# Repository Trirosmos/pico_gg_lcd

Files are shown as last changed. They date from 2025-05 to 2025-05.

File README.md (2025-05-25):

## Pico GG LCD

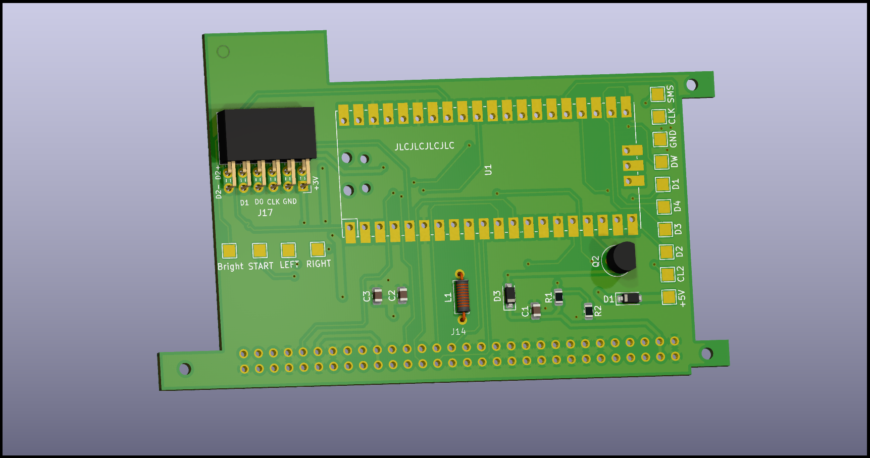
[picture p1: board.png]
install_image


RP2040-based Game Gear screen replacement kit.
Even a cheapo modern LCD has much, much, much better contrast ratio than the OG screen.

## Building the software

Clone this repository and pull all submodules:
```Bash
git clone https://github.com/Trirosmos/pico_gg_lcd
cd pico_gg_lcd
git submodule update --init --recursive
```

Then, run `sw/build.sh`:

```Bash
cd sw
mkdir build
cd build
cmake ../CMakeLists.txt
make
```

This should generate an uf2 file you can upload to the RP2040;

## Building the hardware

Componentes you'll need and their approximate cost:

- Pico GG LCD PCB ($5)
- [PMOD HDMI adapter board](https://aliexpress.com/w/wholesale-pmod%2525252dhdmi.html?spm=a2g0o.detail.search.0) ($4) 
- [54-pin FPC connector adapter board](https://aliexpress.com/item/32827105259.html) ($2)
- [LQ035NC111 LCD module](https://aliexpress.com/w/wholesale-LQ035NC111.html?spm=a2g0o.home.search.0) ($10)
- [RP2040 board that exposes all 30 GPIOs](https://aliexpress.com/item/1005003796653297.html) ($4)
- BS170 or similar NMOSFET ($0.3)
- ~470uH axial THT inductor ($0.2)
- 2x SOD-123 Schottky diode ($0.4)
- 10k 0805 resistor ($0.05)
- 100k 0805 resistor ($0.05)
- 100nF 0805 resistor ($0.05)
- 100uF 0805 resistor ($0.05)
- 22uF 0805 resistor ($0.05)

Total approximate BOM cost: $26

First assemble passive components and transistor, then the RP2040 board and leave the FPC connector to be connected last.
The final board should look something like this, sans the bodge wire:

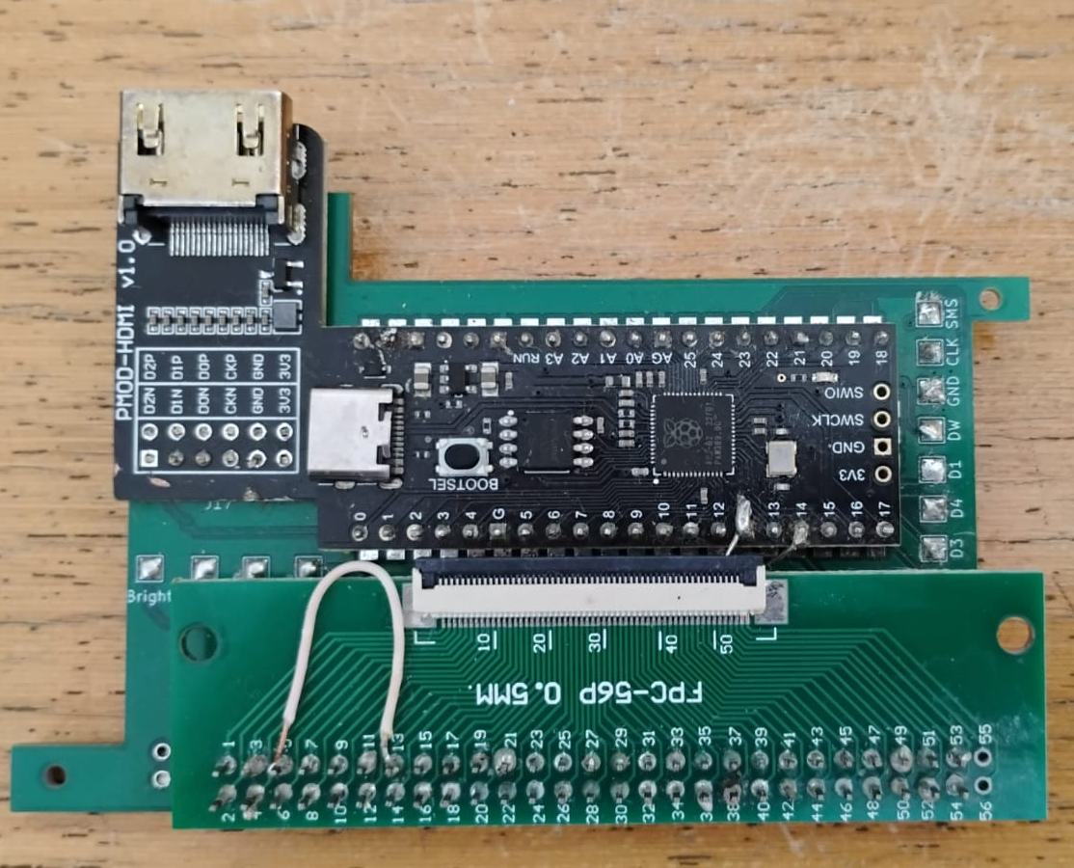
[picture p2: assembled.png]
board_assembly


## How Game Gear video signals work

The Game Gear ASIC generates digital video signals that the LCD drivers in the LCD ribbon use to drive the actual display segments.

In NTSC mode, i.e, when test pad T10 is connected to +5V, the timings of the signals from the ASIC closely resemble what one would expect from a console like the Master System. All screen replacement kits run the Game Gear in this mode, as far as I'm aware. 

The communication protocol used between the ASIC and the LCD drivers in this mode is [well documented](https://www.retrosix.wiki/va0va1-lcd-interface-game-gear) and essentially boils down to:

- 32 MHz pixel clock (same as the main system clock)
- 4 bit data bus carrying one channel of color data at a time
- VSync signal
- HSync signal

## How the RP2040 captures GG video

One of the PIOs is takes alongside three DMA channels with building a live framebuffer in RAM with the image data the GG is sending out.

Three PIO SMs are used in the following manner:

- SM0 detects when a frame starts and triggers an IRQ.
- SM1 detects the IRQ from SM0 and starts detecting HSync pulses. It triggers an IRQ when it does.
- SM2 detects the IRQ from SM1 and proceeds to capture pixel data and push it out to the RX FIFO.

One of the DMA channels then takes the 12bpp pixel data from the PIO RX FIFO and saves it into RAM.

Finally, one of the CPU cores upscales the image and sends it out to the LCD.

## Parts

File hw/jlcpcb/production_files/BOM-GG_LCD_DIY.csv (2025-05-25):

Comment | Designator | Footprint | LCSC
Conn_02x06_Odd_Even | J17 | PinSocket_2x06_P2.54mm_Horizontal | C124371
D_Schottky | D1 | D_SOD-123 | C8598

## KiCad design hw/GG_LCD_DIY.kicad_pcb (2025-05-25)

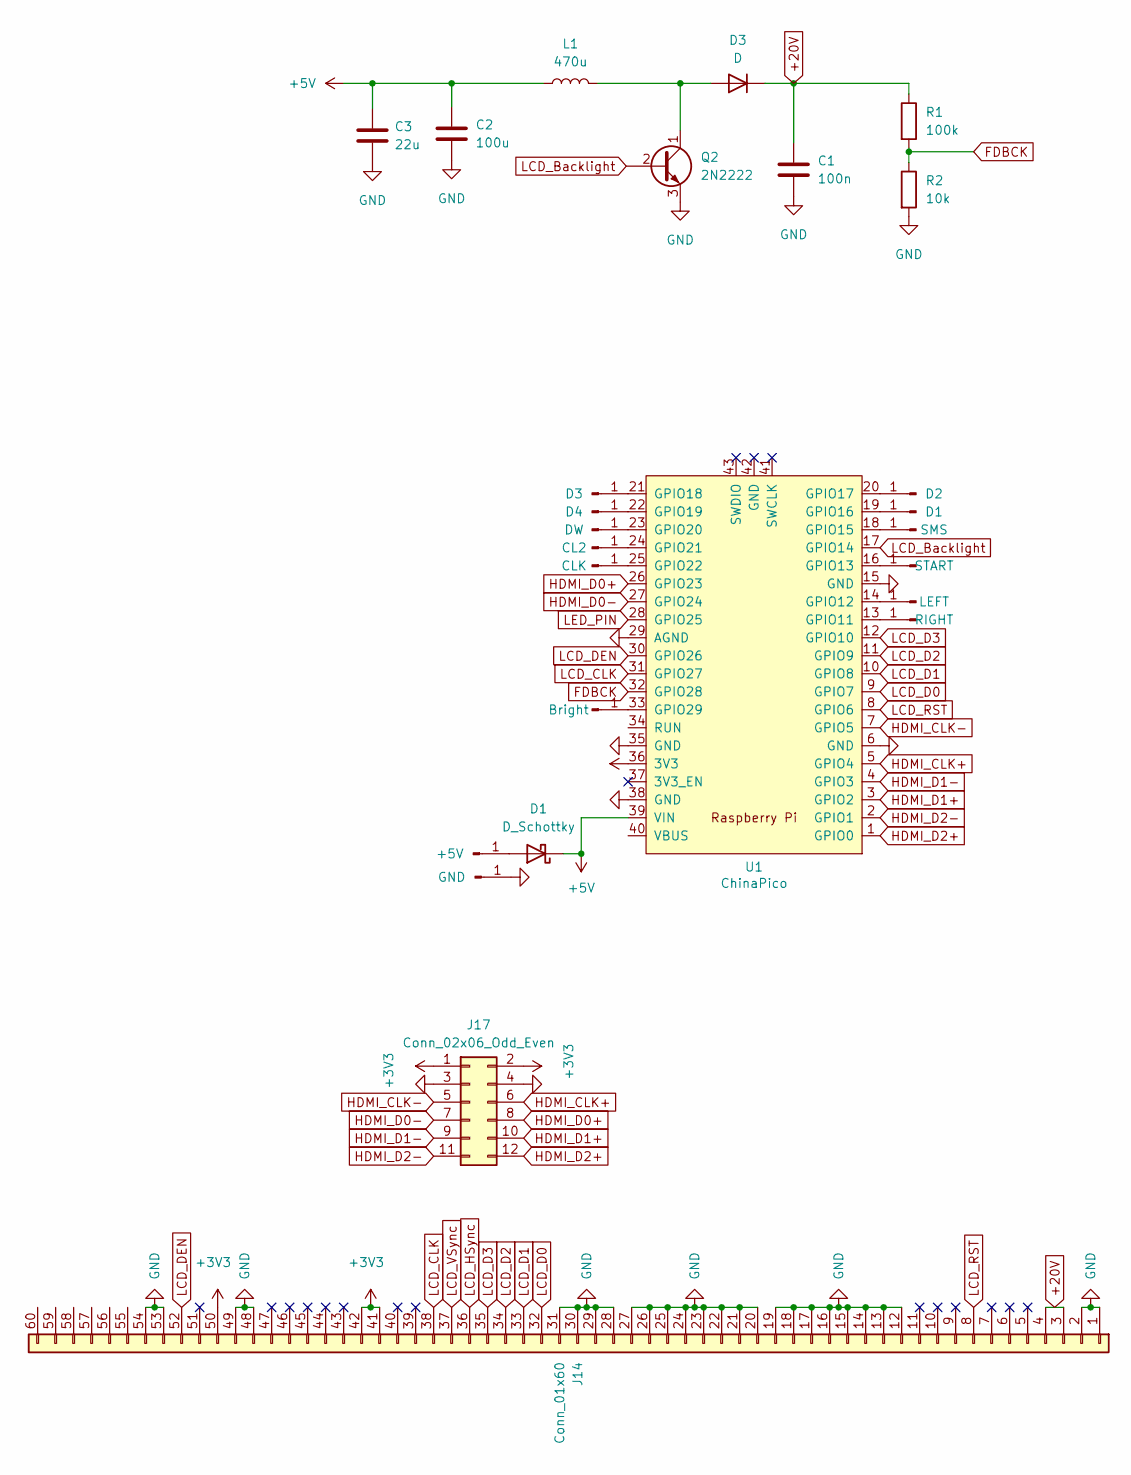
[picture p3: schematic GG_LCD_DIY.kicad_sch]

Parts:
C1: 100n; C_0805_2012Metric
C2: 100u; C_0805_2012Metric
C3: 22u; C_0805_2012Metric
D1: D_Schottky; D_SOD-123
D3: D; D_SOD-123
J1: Bright; TestPoint_Pad_2.0x2.0mm
J2: D1; TestPoint_Pad_2.0x2.0mm
J3: D2; TestPoint_Pad_2.0x2.0mm
J4: D3; TestPoint_Pad_2.0x2.0mm
J5: D4; TestPoint_Pad_2.0x2.0mm
J6: CL2; TestPoint_Pad_2.0x2.0mm
J7: DW; TestPoint_Pad_2.0x2.0mm
J8: CLK; TestPoint_Pad_2.0x2.0mm
J9: SMS; TestPoint_Pad_2.0x2.0mm
J10: LEFT; TestPoint_Pad_2.0x2.0mm
J11: RIGHT; TestPoint_Pad_2.0x2.0mm
J12: START; TestPoint_Pad_2.0x2.0mm
J14: Conn_01x60; FPC_60_Adapter
J15: +5V; TestPoint_Pad_2.0x2.0mm
J16: GND; TestPoint_Pad_2.0x2.0mm
J17: Conn_02x06_Odd_Even; PinSocket_2x06_P2.54mm_Horizontal
L1: 470u; L_Axial_L5.3mm_D2.2mm_P7.62mm_Horizontal_Vishay_IM-1
Q2: 2N2222; TO-92
R1: 100k; R_0805_2012Metric
R2: 10k; R_0805_2012Metric
U1: ChinaPico; RPi_Pico_SMD_TH

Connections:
+3V3: J14.41, J14.42, J14.50, J17.1, J17.2, U1.36 (3V3)
+5V: C2.1, C3.1, D1.1 (K), L1.1, U1.39 (VIN)
+20V: C1.1, D3.1 (K), J14.3, J14.4, R1.1
FDBCK: R1.2, R2.1, U1.32 (GPIO28)
GND: C1.2, C2.2, C3.2, J14.1, J14.2, J14.12, J14.13, J14.14, J14.15, J14.16, J14.17, J14.18, J14.19, J14.20, J14.21, J14.22, J14.23, J14.24, J14.25, J14.26, J14.27, J14.28, J14.29, J14.30, J14.31, J14.48, J14.49, J14.53, J14.54, J16.1, J17.3, J17.4, Q2.3 (E), R2.2, U1.6 (GND), U1.15 (GND), U1.29 (AGND), U1.35 (GND), U1.38 (GND)
HDMI_CLK+: J17.6, U1.5 (GPIO4)
HDMI_CLK-: J17.5, U1.7 (GPIO5)
HDMI_D0+: J17.8, U1.26 (GPIO23)
HDMI_D0-: J17.7, U1.27 (GPIO24)
HDMI_D1+: J17.10, U1.3 (GPIO2)
HDMI_D1-: J17.9, U1.4 (GPIO3)
HDMI_D2+: J17.12, U1.1 (GPIO0)
HDMI_D2-: J17.11, U1.2 (GPIO1)
LCD_Backlight: Q2.2 (B), U1.17 (GPIO14)
LCD_CLK: J14.38, U1.31 (GPIO27)
LCD_D0: J14.32, U1.9 (GPIO7)
LCD_D1: J14.33, U1.10 (GPIO8)
LCD_D2: J14.34, U1.11 (GPIO9)
LCD_D3: J14.35, U1.12 (GPIO10)
LCD_DEN: J14.52, U1.30 (GPIO26)
LCD_HSync: J14.36
LCD_RST: J14.8, U1.8 (GPIO6)
LCD_VSync: J14.37
LED_PIN: U1.28 (GPIO25)
unnamed: D1.2 (A), J15.1
unnamed: D3.2 (A), L1.2, Q2.1 (C)
unnamed: J1.1, U1.33 (GPIO29)
unnamed: J2.1, U1.19 (GPIO16)
unnamed: J3.1, U1.20 (GPIO17)
unnamed: J4.1, U1.21 (GPIO18)
unnamed: J5.1, U1.22 (GPIO19)
unnamed: J6.1, U1.24 (GPIO21)
unnamed: J7.1, U1.23 (GPIO20)
unnamed: J8.1, U1.25 (GPIO22)
unnamed: J9.1, U1.18 (GPIO15)
unnamed: J10.1, U1.14 (GPIO12)
unnamed: J11.1, U1.13 (GPIO11)
unnamed: J12.1, U1.16 (GPIO13)

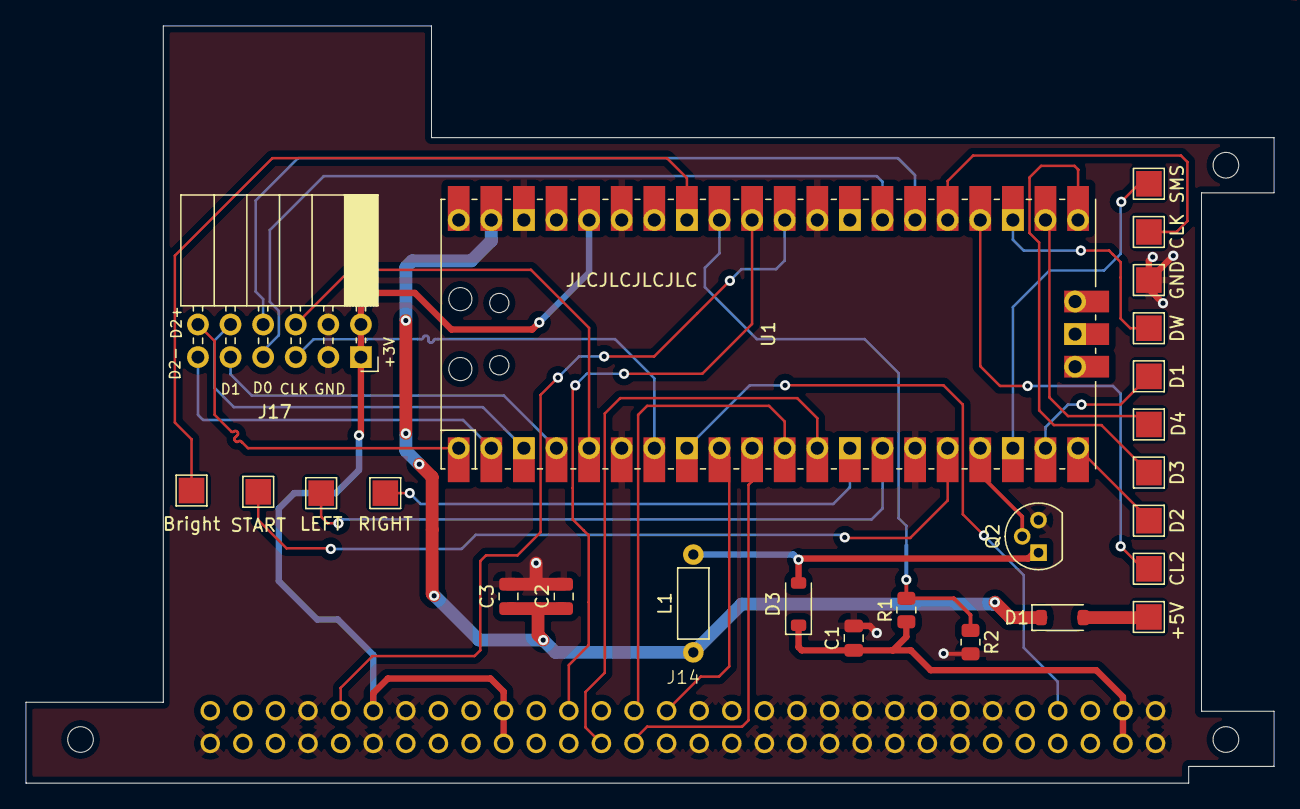
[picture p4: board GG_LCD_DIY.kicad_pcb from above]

Board: 2 copper layers, 97.2 x 59.0 mm, 26 parts (0 on the bottom side), 35 nets.

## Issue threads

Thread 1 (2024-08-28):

Can't compile source code (can you add help in readme ?)

YoGitpp, 2024-08-28:
Hello,

I am trying to compile source code, but it don't work.

By the way, I don't see sdk C definition in .PIO ASM files.
https://github.com/raspberrypi/pico-examples/blob/master/pio/hello_pio/hello.pio
`...
% c-sdk {
...
}`

I don't know what to do with 'memmap_gg.ld'.

In branch ILI9486, one variable is not declared : pixels_a_capturar

Thank you for this project !

Trirosmos, 2024-08-29:
Hi!

As of right now, the project is in a pre-alpha state and a bit far from feature-complete. Once I do finish development on the main featureset, I plan on writing build/installation guides as well as providing release binaries.

In regards to the linker script provided, it's just a custom script I was using as a way of making sure the compiler won't allocate anything in the area of RAM that is being used as a framebuffer. If you want to use it, you should drop it in your `pico/src/rp2_common/pico_standard_link folder`.

As for the ILI9486 branch, it's mostly there for historical reasons as that LCD controller ended up being a pain to work with. It won't see any new development and I don't recommend building a mod based on it.

yeico27, 2024-10-18:
Hello friend, greetings, good job, one question, are you going to release the update with the LQ035NC111 screen?

Trirosmos, 2024-11-15:
> Hello friend, greetings, good job, one question, are you going to release the update with the LQ035NC111 screen?

I will, once I get it to what I'd consider as a _beta_ state.

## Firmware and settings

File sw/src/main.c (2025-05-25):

#include <stdio.h>
#include <string.h>
#include <math.h>
#include <stdint.h>
#include <stdlib.h>
#include "pico/multicore.h"

#include "hardware/pio.h"
#include "hardware/dma.h"
#include "pico/stdlib.h"
#include "pico/time.h"
#include "hardware/vreg.h"
#include "hardware/clocks.h"
#include "hardware/adc.h"
#include "hardware/structs/pwm.h"
#include "hardware/pwm.h"
#include "hardware/interp.h"

#include "../build/gg_capture.pio.h"
#include "../build/lcd_send.pio.h"

#include "libdvi/dvi.h"
#include "libdvi/dvi_serialiser.h"
#include "libdvi/dvi_timing.h"

#define DVI_TIMING dvi_timing_640x480p_60hz

#define dw 20
#define cl2  21
#define led_pin 25
#define SMS_pin 15
#define pixels_in_scanline 300
#define scanlines_in_active_area 192

#define lcd_D0 7
#define lcd_D1 8
#define lcd_D2 9
#define lcd_D3 10
#define lcd_den 26
#define lcd_clk 27
#define lcd_rst 6
#define lcd_backlight 14

#define fdbck 28

#define brightness_pot 29

#define lcd_width 320
#define lcd_channels 3
#define lcd_active_lines 240
#define lcd_hblank_len 95 
#define lcd_blank_lines 3

#define scanlines_to_skip 11

struct dvi_inst dvi0;

static const struct dvi_serialiser_cfg pico_gg_lcd_conf = {
	.pio = pio1,
	.sm_tmds = {1, 2, 3},
	.pins_tmds = {23, 2, 0},
	.pins_clk = 4,
	.invert_diffpairs = false
};

void core1_main() {
	dvi_register_irqs_this_core(&dvi0, DMA_IRQ_0);
	dvi_start(&dvi0);
	dvi_scanbuf_main_12bpp(&dvi0);
}

//Use two framebuffers to prevent tearing
uint16_t * framebuffer = (uint16_t *)(0x20000000 + (1024 * 30));
uint16_t * framebuffer2 = (uint16_t *)(0x20000000 + (1024 * 30) + (pixels_in_scanline * scanlines_in_active_area));

uint32_t pot_history[16];
uint32_t brightness = 0;
uint8_t pwm_backlight_slice;
uint32_t is_gg;
uint32_t gg_now;
uint32_t last_gg;

uint32_t dma_chan0;
uint32_t dma_chan1;
uint32_t dma_chan2;
uint32_t dma_chan3;
uint32_t dma_chan4;
uint32_t dma_chan5;

static inline __attribute__ ((always_inline)) uint32_t unpack(uint32_t rgb_value) {
	uint32_t temp = rgb_value >> 8;
	temp |= rgb_value << 20;
	temp |= rgb_value << 6;
	temp &= 0b111100000011110000001111;

	return temp;
}

__attribute__ ((long_call, section (".time_critical"))) void update_lcd_gg() {	
	//Scanning a frame out into the LCD is faster than ~16ms
	//So, we wait until the console starts sending out a new frame before we update the LCD again
	//If neither of these two DMA channels is busy, then the console must be in vblank
	while(!dma_channel_is_busy(dma_chan0) && !dma_channel_is_busy(dma_chan4)) ;

	uint16_t * curr_framebuffer;

	//See which of the two framebuffer is currently being written to and pick the other one to send to the LCD
	//This introduces a single frame of latency
	if(dma_channel_is_busy(dma_chan0)) curr_framebuffer = framebuffer2;
	else curr_framebuffer = framebuffer;

	pio_sm_put_blocking(pio0, 1, scanlines_in_active_area + 1 - 1);
	pio_sm_exec(pio0, 1, pio_encode_pull(false, true));

	dma_hw->ch[2].transfer_count = pixels_in_scanline * 1;
	dma_hw->ch[3].transfer_count = pixels_in_scanline * 1;

	//Because of the LCD's orientation, we actually need to scan the image out upside down and flipped
	//base points to the bottom right of the original image
	uint32_t base = pixels_in_scanline + 48 - 52 + (pixels_in_scanline * scanlines_in_active_area) - pixels_in_scanline * 51;

	for (uint32_t y = 0; y < 240; y ++)
	{
		//Where in the framebuffer the current scanline starts
		uint32_t y_base = base - ((y * 310) >> 9) * pixels_in_scanline + 256;

		//Tell LCD we're starting the active portion of the scanline
		gpio_put(lcd_den, 0);

		///unpack transforms 0b0000rrrrggggbbbb word into 0bbbb000000gggg000000rrrr word
		//Channel order is changed to bgr because that's what the LCD expects
		//Channel bits are spread out so we can do SIMD-within-a-word
		//The interpolator will do linear interpolation on all three channels at once, using a single 32-bit word
		uint32_t old_pix_value = unpack(curr_framebuffer[y_base] & 4095);

		for (uint32_t x = 0; x < 320; x ++)
		{
			//sub_pixel is a 24.8 bit fixed point coordinate
			uint32_t sub_pixel = (x * 133);

			//Use integer part to pick a pixel from the framebuffer
			uint32_t pixIndex = y_base - (sub_pixel >> 8);
			uint32_t new_pix_value = unpack(curr_framebuffer[pixIndex] & 4095);

			//Values to be interpolated
			interp0->base[0] = old_pix_value;
			interp0->base[1] = new_pix_value;

			//Fractional part of sub_pixel tells the interpolator how much of each pixel to use
			interp0->accum[1] = sub_pixel & 0b11111100;

			uint32_t pix_value = interp0->peek[1];
			//uint32_t pix_value = new_pix_value; //Uncomment this line to use nearest-neighbor instead of linear interpolation

			old_pix_value = new_pix_value;

			//By the time we get here, the PIO is probably gonna be done sending the last pixel anyways
			while(!pio_sm_is_tx_fifo_empty(pio1, 0)) ;

			//This way, we only have to poll on the FIFO status once and then can just blast the three words at once
			//Seems to be significantly faster than pio_sm_put_blocking on each word
			pio_sm_put(pio1, 0, pix_value & 15);
			pix_value >>= 10;
			pio_sm_put(pio1, 0, pix_value & 15);
			pix_value >>= 10;
			pio_sm_put(pio1, 0, pix_value & 15);
		}

		//Signal end of active scanline portion
		gpio_put(lcd_den, 1);

		//Send empty pixels during Hblank
		for(uint32_t wait = 0; wait < lcd_hblank_len; wait ++) {
			pio_sm_put_blocking(pio1, 0, 0);
		}
	}

	//Start of vblank
	gpio_put(lcd_den, 1);

	//Send empty data for the entirety of vblank
	for(uint32_t wait_line = 0; wait_line < lcd_blank_lines; wait_line ++) {
		for(uint32_t pixel = 0; pixel < lcd_width; pixel ++) {
			for(uint32_t channel = 0; channel < lcd_channels; channel ++) {
				pio_sm_put_blocking(pio1, 0, 0);
			}
		}

		for(uint32_t wait = 0; wait < lcd_hblank_len; wait ++) {
			pio_sm_put_blocking(pio1, 0, 0);
		}
	}
}

//The only thing that changes for SMS mode are the scaling constants
//However, putting those values in variables considerably slows down this function
//So, instead, we use magic constants baked into the code
__attribute__ ((long_call, section (".time_critical"))) void update_lcd_sms() {	
    while(!dma_channel_is_busy(dma_chan0) && !dma_channel_is_busy(dma_chan4)) ;
	uint16_t * curr_framebuffer;

	if(dma_channel_is_busy(dma_chan0)) curr_framebuffer = framebuffer2;
	else curr_framebuffer = framebuffer;

	pio_sm_put_blocking(pio0, 1, scanlines_in_active_area + scanlines_to_skip - 1);
	pio_sm_exec(pio0, 1, pio_encode_pull(false, true));

	dma_hw->ch[2].transfer_count = pixels_in_scanline * scanlines_to_skip;
	dma_hw->ch[3].transfer_count = pixels_in_scanline * scanlines_to_skip;

	uint32_t line_counter = 0;
	uint32_t base = pixels_in_scanline + 256 + 48 - 3 + (pixels_in_scanline * scanlines_in_active_area) - pixels_in_scanline * 2;

	for (uint32_t y = 0; y < 240; y ++)
	{
		uint32_t y_base = base - ((y * 413) >> 9) * pixels_in_scanline;

		gpio_put(lcd_den, 0);

		uint32_t old_pix_value = unpack(curr_framebuffer[y_base] & 4095);

		for (uint32_t x = 0; x < 320; x ++)
		{
			uint32_t sub_pixel = (x * 210);
			uint32_t pixIndex = y_base - (sub_pixel >> 8);
			uint32_t new_pix_value = unpack(curr_framebuffer[pixIndex] & 4095);

			interp0->base[0] = old_pix_value;
			interp0->base[1] = new_pix_value;
			interp0->accum[1] = sub_pixel;

			uint32_t pix_value = interp0->peek[1];
			old_pix_value = new_pix_value;

			while(!pio_sm_is_tx_fifo_empty(pio1, 0)) ;

			pio_sm_put(pio1, 0, pix_value & 15);
			pix_value >>= 10;
			pio_sm_put(pio1, 0, pix_value & 15);
			pix_value >>= 10;
			pio_sm_put(pio1, 0, pix_value & 15);
		}

		gpio_put(lcd_den, 1);

		for(uint32_t wait = 0; wait < lcd_hblank_len; wait ++) {
			pio_sm_put_blocking(pio1, 0, 0);
		}
	}

	gpio_put(lcd_den, 1);

	for(uint32_t wait_line = 0; wait_line < lcd_blank_lines; wait_line ++) {
		for(uint32_t pixel = 0; pixel < lcd_width; pixel ++) {
			for(uint32_t channel = 0; channel < lcd_channels; channel ++) {
				pio_sm_put_blocking(pio1, 0, 0);
			}
		}

		for(uint32_t wait = 0; wait < lcd_hblank_len; wait ++) {
			pio_sm_put_blocking(pio1, 0, 0);
		}
	}
}

void config_pios() {
	pio_clear_instruction_memory(pio1);

	//PIO1 is used to send data to the LCD without hogging the CPU
	pio_sm_claim(pio1, 0);

	uint8_t lcd_send = pio_add_program(pio1, &lcd_send_program);
	pio_sm_config lcd_send_config = lcd_send_program_get_default_config(lcd_send);
	sm_config_set_clkdiv(&lcd_send_config, 1);
	sm_config_set_sideset_pins(&lcd_send_config, lcd_clk);
	sm_config_set_out_pins(&lcd_send_config, lcd_D0, 4);
	sm_config_set_out_shift(&lcd_send_config, true, false, 32);
	sm_config_set_in_shift(&lcd_send_config, false, false, 32);

	pio_gpio_init(pio1, lcd_clk);
	pio_gpio_init(pio1, lcd_D0);
	pio_gpio_init(pio1, lcd_D1);
	pio_gpio_init(pio1, lcd_D2);
	pio_gpio_init(pio1, lcd_D3);

	pio_sm_set_pindirs_with_mask(pio1, 0, (1 << lcd_clk), (1 << lcd_clk));
	pio_sm_set_pindirs_with_mask(pio1, 0, (1 << lcd_D0), (1 << lcd_D0));
	pio_sm_set_pindirs_with_mask(pio1, 0, (1 << lcd_D1), (1 << lcd_D1));
	pio_sm_set_pindirs_with_mask(pio1, 0, (1 << lcd_D2), (1 << lcd_D2));
	pio_sm_set_pindirs_with_mask(pio1, 0, (1 << lcd_D3), (1 << lcd_D3));
	pio_sm_init(pio1, 0, lcd_send, &lcd_send_config);
	pio_sm_set_enabled(pio1, 0, true);

	pio_clear_instruction_memory(pio0);

	//PIO0 captures data from the GG's video bus
	pio_sm_claim(pio0, 0);
	pio_sm_claim(pio0, 1);
	pio_sm_claim(pio0, 2);

	uint8_t detect_vblank = pio_add_program(pio0, &detect_vblank_program);
	pio_sm_config detect_vblank_config = detect_vblank_program_get_default_config(detect_vblank);
	sm_config_set_clkdiv(&detect_vblank_config, 1);

	uint8_t detect_hblank = pio_add_program(pio0, &detect_hblank_program);
	pio_sm_config detect_hblank_config = detect_hblank_program_get_default_config(detect_hblank);
	sm_config_set_clkdiv(&detect_hblank_config, 1);

	uint8_t get_data = pio_add_program(pio0, &get_data_program);
	pio_sm_config get_data_config = get_data_program_get_default_config(get_data);
	sm_config_set_clkdiv(&get_data_config, 1);
	sm_config_set_in_pins(&get_data_config, 16);
	sm_config_set_in_shift(&get_data_config, false, false, 32);
	sm_config_set_jmp_pin(&get_data_config, 22);

	pio_sm_init(pio0, 0, detect_vblank, &detect_vblank_config);
	pio_sm_init(pio0, 1, detect_hblank, &detect_hblank_config);
	pio_sm_init(pio0, 2, get_data, &get_data_config);

	pio_sm_put_blocking(pio0, 1, scanlines_in_active_area + scanlines_to_skip - 1);
	pio_sm_exec(pio0, 1, pio_encode_pull(false, true));

	pio_sm_put_blocking(pio0, 2, pixels_in_scanline - 1); 
	pio_sm_exec(pio0, 2, pio_encode_pull(false, true));

	pio_enable_sm_mask_in_sync(pio0, 0b111);
}

uint32_t dummy;

void config_dma() {
	for(uint32_t c = 0; c < 12; c++) {
		dma_channel_cleanup(c);
    dma_channel_unclaim(c);
	}

	//DVI code uses claim_unused_channel, so we must as well, instead of explicitly picking DMA channels
	dma_chan0 = dma_claim_unused_channel(true);
	dma_chan1 = dma_claim_unused_channel(true);
	dma_chan2 = dma_claim_unused_channel(true);
	dma_chan3 = dma_claim_unused_channel(true);
	dma_chan4 = dma_claim_unused_channel(true);
	dma_chan5 = dma_claim_unused_channel(true);

	//PIO0 SM2 is the one that actually sends out pixel data
	dma_channel_config g = dma_channel_get_default_config(dma_chan2);
	channel_config_set_transfer_data_size(&g, DMA_SIZE_16);
	channel_config_set_enable(&g, true);
	channel_config_set_chain_to(&g, dma_chan0);
	channel_config_set_read_increment(&g, false);
	channel_config_set_write_increment(&g, false);
	channel_config_set_dreq(&g, pio_get_dreq(pio0, 2, false));
	dma_channel_configure(
			dma_chan2,
			&g,
			&dummy,
			&pio0_hw->rxf[2],
			//The first few active display scanlines are actually blank
			//We skip them by taking data from the PIO and discarding it into the dummy variable
			//We than chain to dma_chan0 
			pixels_in_scanline * scanlines_to_skip,
			false);

	//Now we can save the scanlines that actually have image data into the framebuffer
	dma_channel_config f = dma_channel_get_default_config(dma_chan0);
	channel_config_set_transfer_data_size(&f, DMA_SIZE_16);
	channel_config_set_enable(&f, true);
	channel_config_set_chain_to(&f, dma_chan1);
	channel_config_set_read_increment(&f, false);
	channel_config_set_write_increment(&f, true);
	channel_config_set_dreq(&f, pio_get_dreq(pio0, 2, false));
	dma_channel_configure(
			dma_chan0,
			&f,
			//Note that we're filling the first framebuffer here
			//There's two of them, for double buffering, so we don't get screen tearing
			&framebuffer[0],
			&pio0_hw->rxf[2],
			//Again, the active area has border scanlines that don't actually contain game graphics
			//We only save the *real* scanlines into the framebuffer
			//Then chain to dma_chan1
			pixels_in_scanline * scanlines_in_active_area,
			false);

	//Reset dma_chan0's write address register to point to the start of framebuffer0
	//Then chain to dma_chan3
	dma_channel_config e = dma_channel_get_default_config(dma_chan1);
	channel_config_set_transfer_data_size(&e, DMA_SIZE_32);
	channel_config_set_enable(&e, true);
	channel_config_set_chain_to(&e, dma_chan3);
	channel_config_set_read_increment(&e, false);
	channel_config_set_write_increment(&e, false);
	dma_channel_configure(
			dma_chan1,
			&e,
			&(dma_hw->ch[dma_chan0].write_addr),
			&framebuffer,
			1,
			false);

	//Skip unwanted lines, but now for the second frame
	g = dma_channel_get_default_config(dma_chan3);
	channel_config_set_transfer_data_size(&g, DMA_SIZE_16);
	channel_config_set_enable(&g, true);
	channel_config_set_chain_to(&g, dma_chan4);
	channel_config_set_read_increment(&g, false);
	channel_config_set_write_increment(&g, false);
	channel_config_set_dreq(&g, pio_get_dreq(pio0, 2, false));
	dma_channel_configure(
			dma_chan3,
			&g,
			&dummy,
			&pio0_hw->rxf[2],
			pixels_in_scanline * scanlines_to_skip,
			false);

	//Save active scanlines into second framebuffer
	f = dma_channel_get_default_config(dma_chan4);
	channel_config_set_transfer_data_size(&f, DMA_SIZE_16);
	channel_config_set_enable(&f, true);
	channel_config_set_chain_to(&f, dma_chan5);
	channel_config_set_read_increment(&f, false);
	channel_config_set_write_increment(&f, true);
	channel_config_set_dreq(&f, pio_get_dreq(pio0, 2, false));
	dma_channel_configure(
			dma_chan4,
			&f,
			&framebuffer2[0],
			&pio0_hw->rxf[2],
			pixels_in_scanline * scanlines_in_active_area,
			false);

	//Reset dma_chan4's write address and chain into dma_chan2 to restart the whole DMA chain
	e = dma_channel_get_default_config(dma_chan5);
	channel_config_set_transfer_data_size(&e, DMA_SIZE_32);
	channel_config_set_enable(&e, true);
	channel_config_set_chain_to(&e, dma_chan2);
	channel_config_set_read_increment(&e, false);
	channel_config_set_write_increment(&e, false);
	dma_channel_configure(
			dma_chan5,
			&e,
			&(dma_hw->ch[dma_chan4].write_addr),
			&framebuffer2,
			1,
			false);
}

void config_backlight_supply(uint8_t pwm_backlight_slice) {
	adc_init();
	adc_select_input(fdbck - 26);
	adc_gpio_init(fdbck);
	adc_run(true);
	adc_fifo_setup(true, false, 0, 0, 0);

	pwm_hw->slice[pwm_backlight_slice].cc = 250;
	sleep_ms(50);

	float tensao_media = 0;

	/*while(tensao_media < 19 || tensao_media > 20) {
		for(uint32_t m = 0; m < 5; m++) {
			sleep_ms(2);
			tensao_media += adc_fifo_get();
		}

		tensao_media *= 3.3;
		tensao_media *= 11;
		tensao_media /= 5;
		tensao_media /= 4095;

		if(tensao_media < 10) {
			pwm_hw->slice[pwm_backlight_slice].cc += 50;
		}
		else if(tensao_media < 15) {
			pwm_hw->slice[pwm_backlight_slice].cc += 20;
		}
		else if(tensao_media < 19) {
			pwm_hw->slice[pwm_backlight_slice].cc += 10;
		}
		else if(tensao_media > 21) {
			pwm_hw->slice[pwm_backlight_slice].cc -= 20;
		}
		else if(tensao_media > 19) {
			pwm_hw->slice[pwm_backlight_slice].cc -= 10;
		}

		gpio_put(led_pin, !gpio_get(led_pin));
	}*/
	pwm_hw->slice[pwm_backlight_slice].cc = 3500;
	//pwm_hw->slice[pwm_backlight_slice].cc = 20;
}

uint8_t config_backlight_pwm() {
	gpio_set_function(lcd_backlight, GPIO_FUNC_PWM);
	pwm_backlight_slice = pwm_gpio_to_slice_num(lcd_backlight);

	pwm_config config = pwm_get_default_config();
	pwm_config_set_phase_correct(&config, false);
	pwm_config_set_clkdiv_int(&config, 1);
	pwm_config_set_clkdiv_mode(&config, PWM_DIV_FREE_RUNNING);
	pwm_config_set_wrap(&config, (DVI_TIMING.bit_clk_khz * 1000) / 50000);
	pwm_init(pwm_backlight_slice, &config, true);

	return pwm_backlight_slice;
}

void config_interp() {
	//Claim both lanes
	interp_claim_lane_mask(interp0, 0b11);

	interp_config cfg = interp_default_config();
	//Only interpolator 0 has " blend " mode, which does linear interpolation
	interp_config_set_blend(&cfg, true);
	interp_set_config(interp0, 0, &cfg);

	cfg = interp_default_config();
	interp_set_config(interp0, 1, &cfg);
}

void init_lcd() {
	gpio_put(lcd_rst, 1);
	sleep_ms(10);
	gpio_put(lcd_rst, 0);
	sleep_ms(10);
	gpio_put(lcd_rst, 1);
}

void fill_framebuffer_with_test_pattern() {
	for(uint32_t y = 0; y < scanlines_in_active_area; y++) {
		for(uint32_t x = 0; x < pixels_in_scanline; x++) {
			uint16_t pixel = 0;

			if(x > 150 && y > 96) pixel |= 15;
			if(x < 150 && y < 96) pixel |= 15;

			if(x < 150 && y > 96) pixel |= (15 << 8);
			if(x <= 150 && y <= 96) pixel |= (15 << 8);

			if(x > 150 && y < 96) pixel |= (15 << 4);
			if(x <= 150 && y <= 96) pixel |= (15 << 4);

			framebuffer[x + y * pixels_in_scanline] = pixel;
			framebuffer2[x + y * pixels_in_scanline] = ~pixel;
		}
	}
}

int main() {
	vreg_set_voltage(VREG_VOLTAGE_1_10);
	set_sys_clock_khz(DVI_TIMING.bit_clk_khz, true);
	stdio_init_all();

	gpio_init_mask(0b11111111111111111111111111111111);
	gpio_set_dir_out_masked(1 << led_pin);
	gpio_set_dir_out_masked(1 << lcd_rst);
	gpio_set_dir_out_masked(1 << lcd_den);
	gpio_set_dir_out_masked(1 << lcd_backlight);

	uint8_t pwm_backlight_slice = config_backlight_pwm();
	config_backlight_supply(pwm_backlight_slice);

	//These functions MUST be called before dvi_init, since they unclaim all DMA channels and clear PIO memory
	init_lcd();
	config_pios();
	config_dma();
	config_interp();

	dvi0.timing = &DVI_TIMING;
	dvi0.ser_cfg = pico_gg_lcd_conf;
	dvi_init(&dvi0, next_striped_spin_lock_num(), next_striped_spin_lock_num());

	multicore_launch_core1(core1_main);

	gpio_put(lcd_den, 1);
	gpio_put(lcd_clk, 0);
	gpio_put(lcd_backlight, 0);

	adc_init();
	adc_select_input(brightness_pot - 26);
	adc_gpio_init(brightness_pot);
	adc_run(true);
	adc_fifo_setup(true, false, 0, 0, 0);

	fill_framebuffer_with_test_pattern();

	dma_channel_start(dma_chan2);

	while(1) {
		last_gg = gg_now;
		gg_now = !gpio_get(SMS_pin);

		if(last_gg == gg_now) is_gg = gg_now;

		uint32_t start = time_us_32();
		if(!is_gg) update_lcd_gg();
		else update_lcd_sms();
		uint32_t end = time_us_32();

		uint32_t avg = 0;
		for (uint32_t c = 15; c > 0; c--)
		{
			avg += pot_history[c];
			pot_history[c] = pot_history[c - 1];
		}
		pot_history[0] = adc_fifo_get();
		avg += pot_history[0];
		avg >>= 4;
		brightness = avg;
		brightness *= 6;

		//printf("Pot: %i\n", brightness);
		printf("Rendering time: %i us\n", end - start);
	}

	return 0;
}
 

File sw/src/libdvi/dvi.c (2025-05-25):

#include <stdlib.h>
#include "hardware/dma.h"
#include "hardware/irq.h"

#include "dvi.h"
#include "dvi_timing.h"
#include "dvi_serialiser.h"
#include "tmds_encode.h"

// Time-critical functions pulled into RAM but each in a unique section to
// allow garbage collection
#define __dvi_func(f) __not_in_flash_func(f)
#define __dvi_func_x(f) __scratch_x(__STRING(f)) f
#define pixels_in_scanline 300
#define scanlines_in_active_area 192

// We require exclusive use of a DMA IRQ line. (you wouldn't want to share
// anyway). It's possible in theory to hook both IRQs and have two DVI outs.
static struct dvi_inst *dma_irq_privdata[2];
static void dvi_dma0_irq();
static void dvi_dma1_irq();

void dvi_init(struct dvi_inst *inst, uint spinlock_tmds_queue, uint spinlock_colour_queue) {
	dvi_timing_state_init(&inst->timing_state);
	dvi_serialiser_init(&inst->ser_cfg);
	for (int i = 0; i < N_TMDS_LANES; ++i) {
		inst->dma_cfg[i].chan_ctrl = dma_claim_unused_channel(true);
		inst->dma_cfg[i].chan_data = dma_claim_unused_channel(true);
		inst->dma_cfg[i].tx_fifo = (void*)&inst->ser_cfg.pio->txf[inst->ser_cfg.sm_tmds[i]];
		inst->dma_cfg[i].dreq = pio_get_dreq(inst->ser_cfg.pio, inst->ser_cfg.sm_tmds[i], true);
	}
	inst->late_scanline_ctr = 0;
	inst->tmds_buf_release_next = NULL;
	inst->tmds_buf_release = NULL;
	queue_init_with_spinlock(&inst->q_tmds_valid,   sizeof(void*),  8, spinlock_tmds_queue);
	queue_init_with_spinlock(&inst->q_tmds_free,    sizeof(void*),  8, spinlock_tmds_queue);
	queue_init_with_spinlock(&inst->q_colour_valid, sizeof(void*),  8, spinlock_colour_queue);
	queue_init_with_spinlock(&inst->q_colour_free,  sizeof(void*),  8, spinlock_colour_queue);

	dvi_setup_scanline_for_vblank(inst->timing, inst->dma_cfg, true, &inst->dma_list_vblank_sync);
	dvi_setup_scanline_for_vblank(inst->timing, inst->dma_cfg, false, &inst->dma_list_vblank_nosync);
	dvi_setup_scanline_for_active(inst->timing, inst->dma_cfg, (void*)SRAM_BASE, &inst->dma_list_active);
	dvi_setup_scanline_for_active(inst->timing, inst->dma_cfg, NULL, &inst->dma_list_error);

	for (int i = 0; i < DVI_N_TMDS_BUFFERS; ++i) {
		void *tmdsbuf;
#if DVI_MONOCHROME_TMDS
		tmdsbuf = malloc(inst->timing->h_active_pixels / DVI_SYMBOLS_PER_WORD * sizeof(uint32_t));
#else
		tmdsbuf = malloc(3 * inst->timing->h_active_pixels / DVI_SYMBOLS_PER_WORD * sizeof(uint32_t));
#endif
		if (!tmdsbuf)
			panic("TMDS buffer allocation failed");
		queue_add_blocking_u32(&inst->q_tmds_free, &tmdsbuf);
	}
}

// The IRQs will run on whichever core calls this function (this is why it's
// called separately from dvi_init)
void dvi_register_irqs_this_core(struct dvi_inst *inst, uint irq_num) {
	uint32_t mask_sync_channel = 1u << inst->dma_cfg[TMDS_SYNC_LANE].chan_data;
	uint32_t mask_all_channels = 0;
	for (int i = 0; i < N_TMDS_LANES; ++i)
		mask_all_channels |= 1u << inst->dma_cfg[i].chan_ctrl | 1u << inst->dma_cfg[i].chan_data;

	dma_hw->ints0 = mask_sync_channel;
	if (irq_num == DMA_IRQ_0) {
		hw_write_masked(&dma_hw->inte0, mask_sync_channel, mask_all_channels);
		dma_irq_privdata[0] = inst;
		irq_set_exclusive_handler(DMA_IRQ_0, dvi_dma0_irq);
	}
	else {
		hw_write_masked(&dma_hw->inte1, mask_sync_channel, mask_all_channels);
		dma_irq_privdata[1] = inst;
		irq_set_exclusive_handler(DMA_IRQ_1, dvi_dma1_irq);
	}
	irq_set_enabled(irq_num, true);
}

// Set up control channels to make transfers to data channels' control
// registers (but don't trigger the control channels -- this is done either by
// data channel CHAIN_TO or an initial write to MULTI_CHAN_TRIGGER)
static inline void __attribute__((always_inline)) _dvi_load_dma_op(const struct dvi_lane_dma_cfg dma_cfg[], struct dvi_scanline_dma_list *l) {
	for (int i = 0; i < N_TMDS_LANES; ++i) {
		dma_channel_config cfg = dma_channel_get_default_config(dma_cfg[i].chan_ctrl);
		channel_config_set_ring(&cfg, true, 4); // 16-byte write wrap
		channel_config_set_read_increment(&cfg, true);
		channel_config_set_write_increment(&cfg, true);
		dma_channel_configure(
			dma_cfg[i].chan_ctrl,
			&cfg,
			&dma_hw->ch[dma_cfg[i].chan_data],
			dvi_lane_from_list(l, i),
			4, // Configure all 4 registers then halt until next CHAIN_TO
			false
		);
	}
}

// Setup first set of control block lists, configure the control channels, and
// trigger them. Control channels will subsequently be triggered only by DMA
// CHAIN_TO on data channel completion. IRQ handler *must* be prepared before
// calling this. (Hooked to DMA IRQ0)
void dvi_start(struct dvi_inst *inst) {
	_dvi_load_dma_op(inst->dma_cfg, &inst->dma_list_vblank_nosync);
	dma_start_channel_mask(
		(1u << inst->dma_cfg[0].chan_ctrl) |
		(1u << inst->dma_cfg[1].chan_ctrl) |
		(1u << inst->dma_cfg[2].chan_ctrl));

	// We really don't want the FIFOs to bottom out, so wait for full before
	// starting the shift-out.
	for (int i = 0; i < N_TMDS_LANES; ++i)
		while (!pio_sm_is_tx_fifo_full(inst->ser_cfg.pio, inst->ser_cfg.sm_tmds[i]))
			tight_loop_contents();
	dvi_serialiser_enable(&inst->ser_cfg, true);
}


static inline void __dvi_func_x(_dvi_prepare_scanline_12bpp)(struct dvi_inst *inst, uint32_t *scanbuf) {
	uint32_t *tmdsbuf;
	queue_remove_blocking_u32(&inst->q_tmds_free, &tmdsbuf);
	uint pixwidth = inst->timing->h_active_pixels;
	uint words_per_channel = pixwidth / DVI_SYMBOLS_PER_WORD;
	tmds_encode_data_channel_16bpp(scanbuf, tmdsbuf + 0 * words_per_channel, pixwidth / 2, DVI_12BPP_BLUE_MSB,  DVI_12BPP_BLUE_LSB );
	tmds_encode_data_channel_16bpp(scanbuf, tmdsbuf + 1 * words_per_channel, pixwidth / 2, DVI_12BPP_GREEN_MSB, DVI_12BPP_GREEN_LSB);
	tmds_encode_data_channel_16bpp(scanbuf, tmdsbuf + 2 * words_per_channel, pixwidth / 2, DVI_12BPP_RED_MSB,   DVI_12BPP_RED_LSB  );
	queue_add_blocking_u32(&inst->q_tmds_valid, &tmdsbuf);
}

uint32_t scanbuf_pointer = 0;
uint16_t empty_scanline[320];

uint16_t * scanbuf = (uint16_t *)(0x20000000 + (1024 * 30));
uint16_t * scanbuf2 = (uint16_t *)(0x20000000 + (pixels_in_scanline * scanlines_in_active_area * 2) + (1024 * 30));
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

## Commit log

2024-06-24 Start custom PCB
    [Pico.skp, Pico_GG_LCD.kicad_pcb, Pico_GG_LCD.kicad_sch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]
2024-06-29 Start work on standalone PCB
    [Pico_GG_LCD.kicad_pcb, Pico_GG_LCD.kicad_sch]
2024-06-29 Add HDMI connector
    [Pico_GG_LCD.kicad_pcb, Pico_GG_LCD.kicad_sch]
2024-06-29 Fix HDMI connector orientation
    [Pico_GG_LCD.kicad_pcb, Pico_GG_LCD.kicad_sch]
2024-06-29 Define PCB shape to fit in GG motherboard screwholes
    [Pico_GG_LCD.kicad_pcb]
2024-06-29 Leave HDMI connector out of the way of the LCD ribbon
    [Pico_GG_LCD.kicad_pcb]
2024-06-30 Add component values for boost converter
    [Pico_GG_LCD.kicad_pcb, Pico_GG_LCD.kicad_sch]
2024-06-30 Can't forget about the flash memory, duh
    [Pico_GG_LCD.kicad_pcb, Pico_GG_LCD.kicad_sch]
2024-06-30 Add JLCPCB manufacturing data
    [BOM-Pico_GG_LCD.csv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]
2024-06-30 Add IC pin marker
    [Pico_GG_LCD.kicad_pcb]
2024-06-30 Fix HDMI connections (thanks, willbritton)
    [Pico_GG_LCD.kicad_pcb, Pico_GG_LCD.kicad_sch]
2024-06-30 Add indicator LED
    [Pico_GG_LCD.kicad_pcb, Pico_GG_LCD.kicad_sch]
2024-07-05 DIY board version
    [BOM-Pico_GG_LCD.csv, GG_LCD_DIY.kicad_pcb, GG_LCD_DIY.kicad_sch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]
2024-07-05 Nudge PMOD connector a bit
    [GG_LCD_DIY.kicad_pcb]
2024-08-17 New FPC connector position; Fix LCD pin order;
2024-08-29 Update board image for DIY version
2025-05-25 LQ035NC111 release
    [BOM-GG_LCD_DIY.csv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]
